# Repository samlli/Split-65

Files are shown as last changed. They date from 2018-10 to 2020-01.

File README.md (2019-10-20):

# split_65
split_65 (insert creative name here) is a split, 65% layout keyboard designed for improved ergonomics and typing comfort over extended periods of time.

<figure>
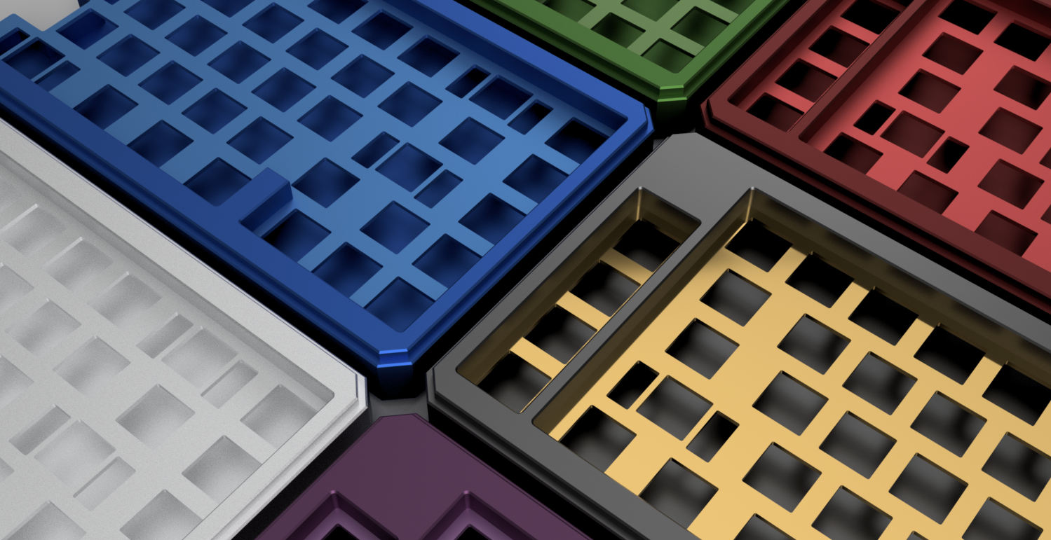
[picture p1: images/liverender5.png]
homepage
  
  <figcaption><i>maybe grey's not your taste - red and green and blue, oh my!</i></figcaption>
</figure>

It aims to remain loyal to the standard ansi layout, making the split_65 second nature to use.  The sturdy two part aluminum construction ensures that the keyboard will survive whatever torture is thrown at it over the years

<figure>
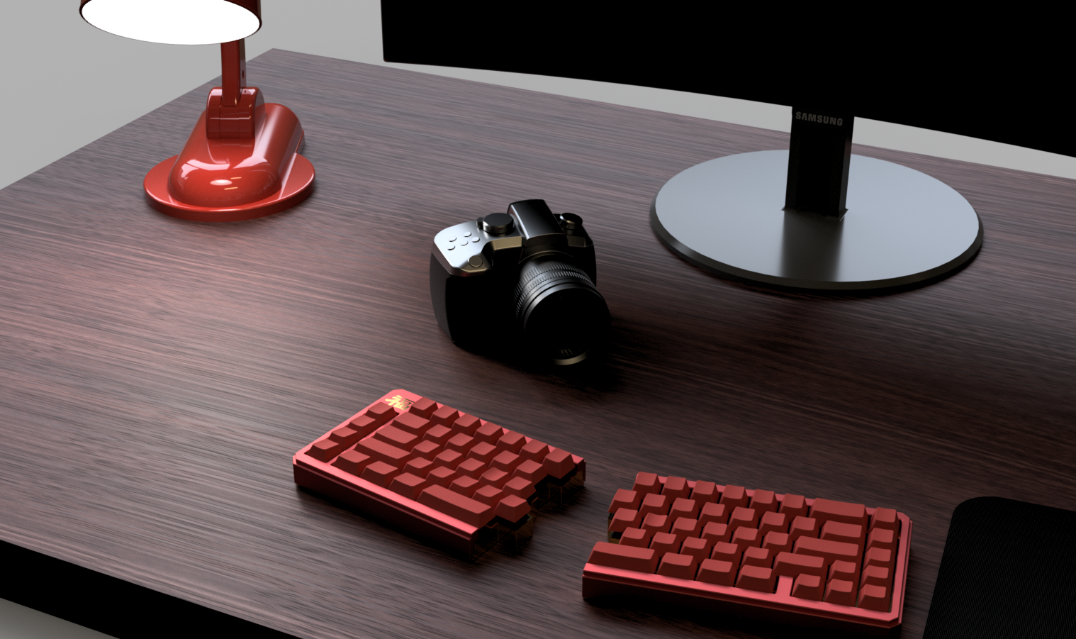
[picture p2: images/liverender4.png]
on the desk
  
  <figcaption><i>feels right at home on any desk</i></figcaption>
</figure>

## technical details

<figure>
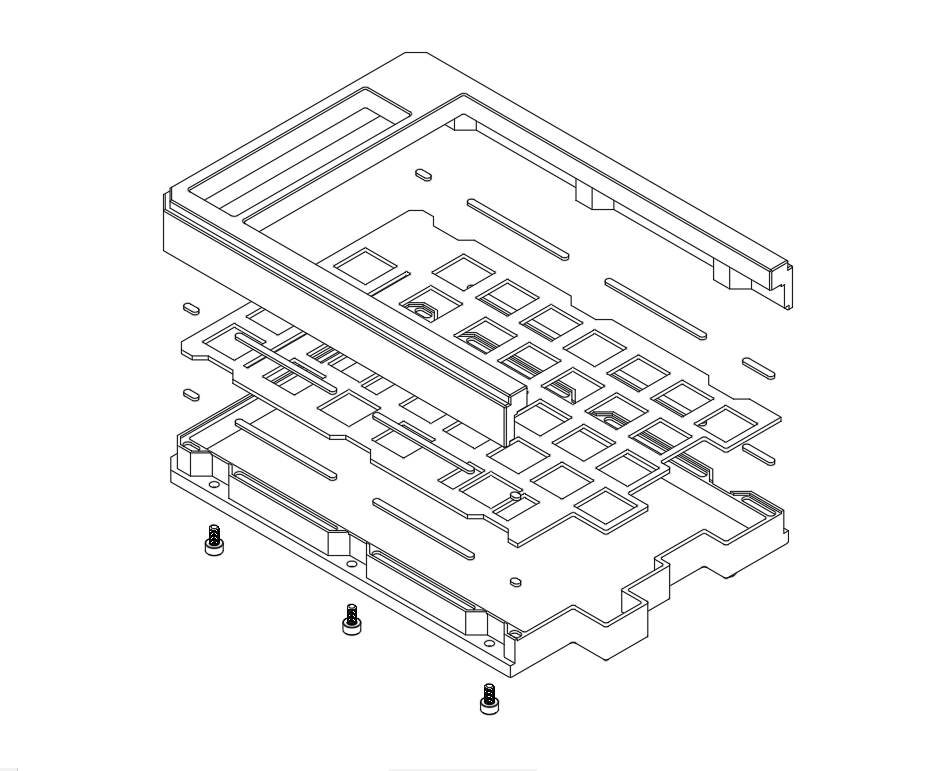
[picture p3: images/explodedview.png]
exploded view
  
  <figcaption><i>I just wanted to show off an exploded view</i></figcaption>
</figure>

Possible layouts are shown below - the pcb offers stepped caps lock, tsangan, and split backspace support, and users are free to mix and match layouts as needed to suit their needs.

<figure>
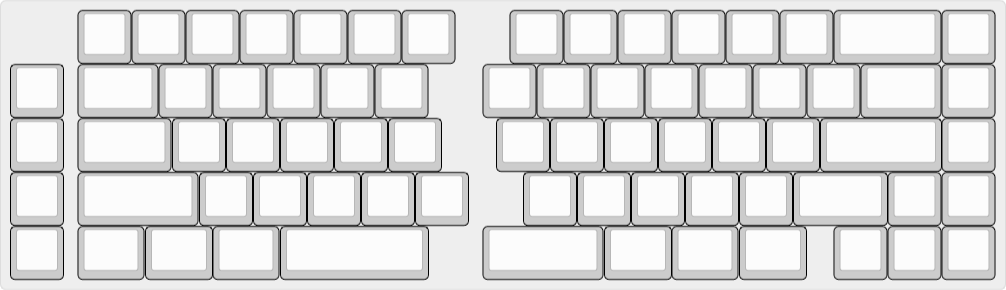
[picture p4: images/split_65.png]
layout
  
  <figcaption><i>possible layout one</i></figcaption>
</figure>

<figure>
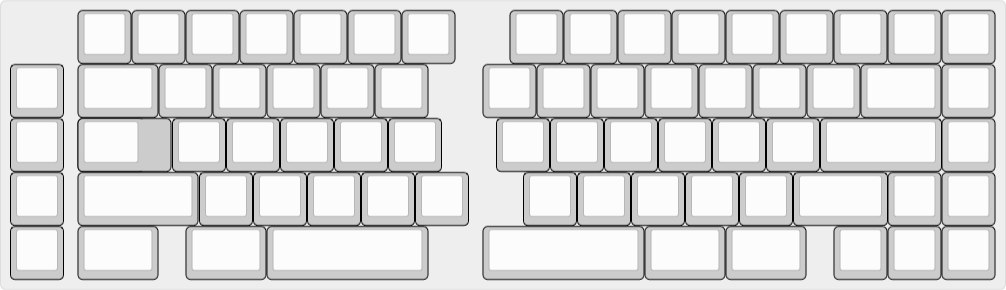
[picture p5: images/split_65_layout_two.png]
layout two
  
  <figcaption><i>possible layout two</i></figcaption>
</figure>

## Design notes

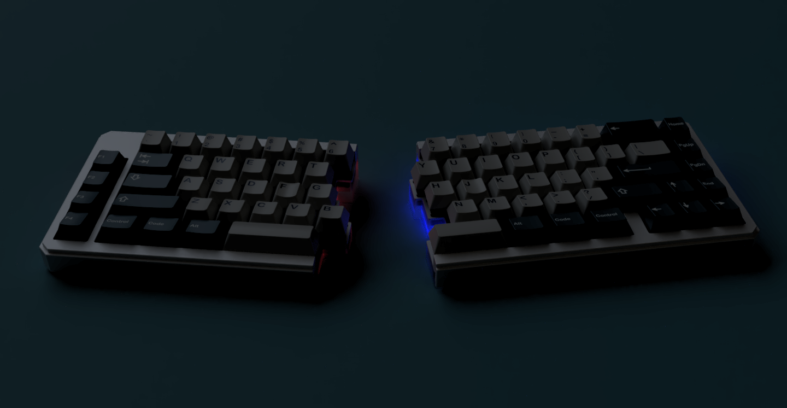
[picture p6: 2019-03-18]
images/ta90_poly_blank_render_1.png

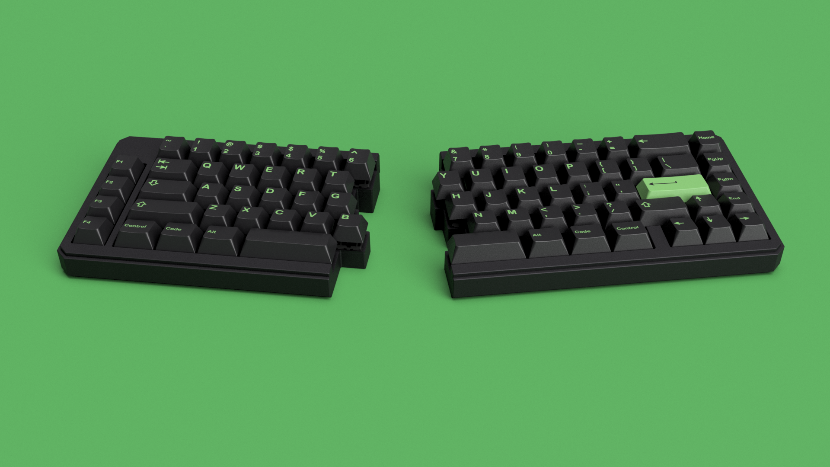
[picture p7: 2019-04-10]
images/terminal_blank_render_3.png

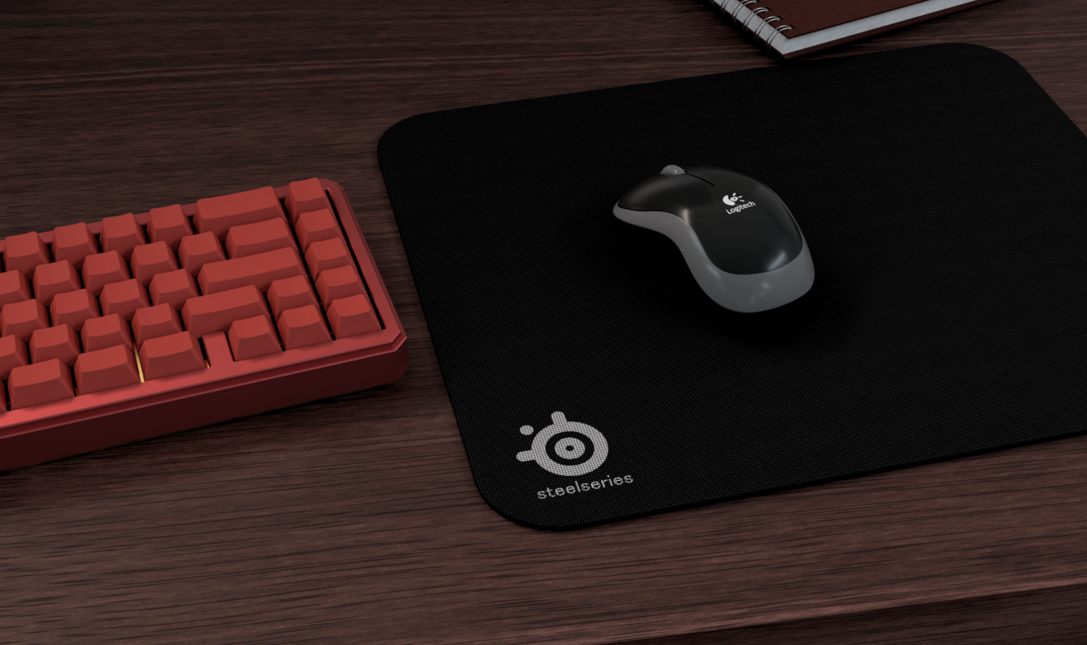
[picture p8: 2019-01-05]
images/liverender3.png

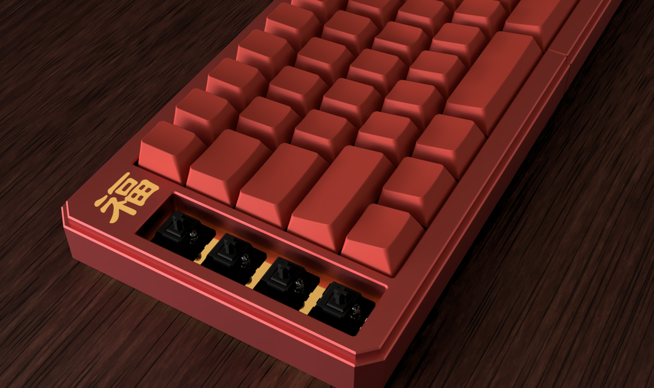
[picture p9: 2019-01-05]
images/render2.png

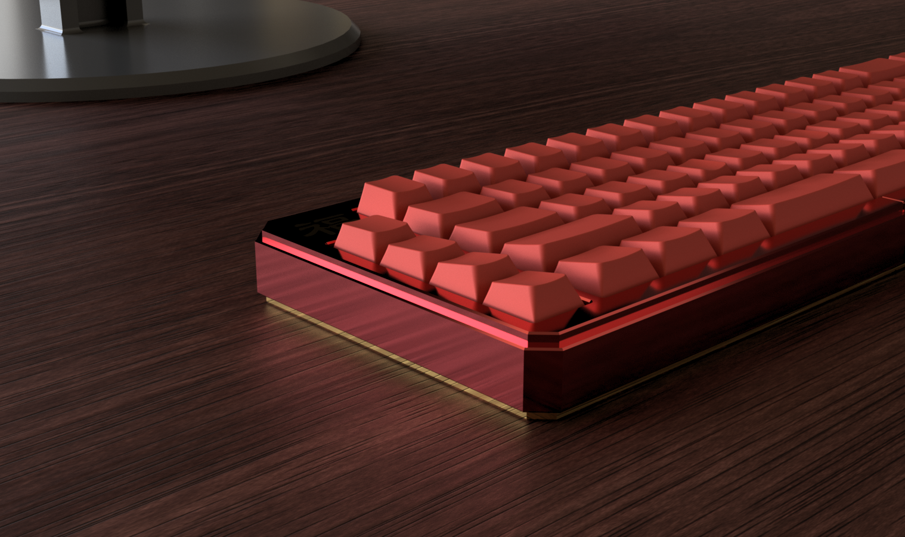
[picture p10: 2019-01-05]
images/liverender2.png

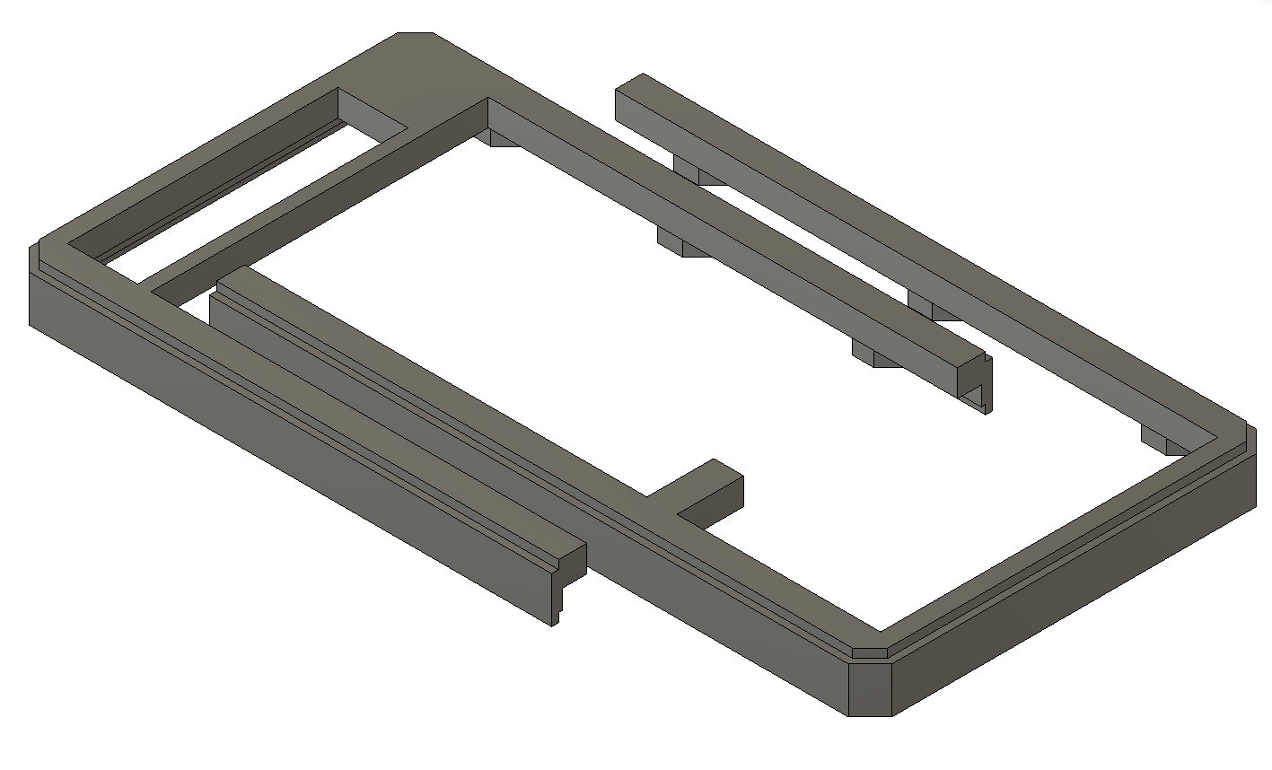
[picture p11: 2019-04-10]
images/tops.png

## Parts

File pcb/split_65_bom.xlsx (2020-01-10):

Designator | Manufacturer Part Number or Seeed SKU | Qty | Link
C1,C2,C8,C9 | 302010143 | 4
C3,C10 | 302010139 | 2
C4,C5,C6,C11,C12,C13 | 302010138 | 6
C7,C14 | 302010103 | 2
D0,D1,D2,D3,D4,D5,D6,D7,D8,D9,D10,D11,D12,D13,D14,D15,D16,D17,D18,D19,D20,D21,D22,D23,D24,D25,D26,D27,D28,D29,D30,D31,D32,D33,D35,D36,D37,D38,D39,D40,D41,D42,D43,D44,D45,D46,D47,D48,D49,D50,D51,D52,D53,D54,D55,D56,D57,D58,D59,D60,D61,D62,D63,D64,D65,D66,D67,D68,D69,D70,D71,D72,D73,D74,D75 | MMSD4148T1G | 75
D34,D76 | 304020028 | 2
F1,F2 | 307010002 | 2
R8,R9 | 301010306 | 2
R18 | 301010367 | 1
R24,R40,R69,R88 | 301010361 | 4
R38,R39,R86,R87 | 301010329 | 4
R41,R42,R89,R90 | 301012180 | 4
U1,U3 | ATMEGA32U4-AU | 2
U2,U4 | 304050022 | 2
USB1,USB2 | TYPE-C-31-M-12 | 2 | https://lcsc.com/product-detail/USB-Type-C_Korean-Hroparts-Elec-TYPE-C-31-M-12_C165948.html
Y1,Y2 | 306010049 | 2

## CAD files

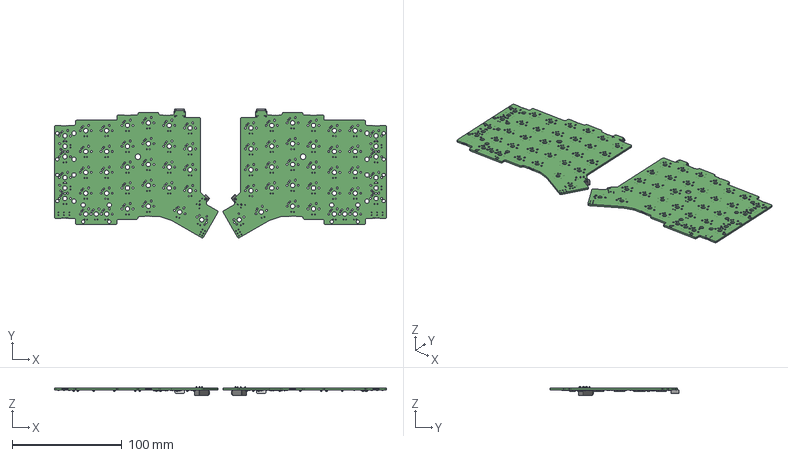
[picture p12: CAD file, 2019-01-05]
pcb/split_65.step
303.2 x 117.9 x 8.00 mm

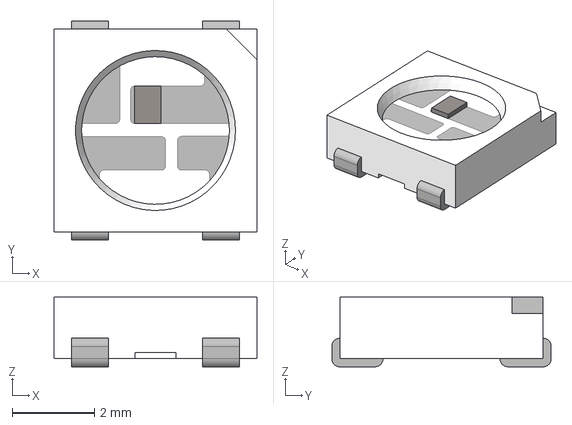
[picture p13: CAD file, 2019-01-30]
pcb/WS2812B.pretty-master/WS2812_RGB_LED_updated.stp
4.95 x 5.35 x 1.70 mm

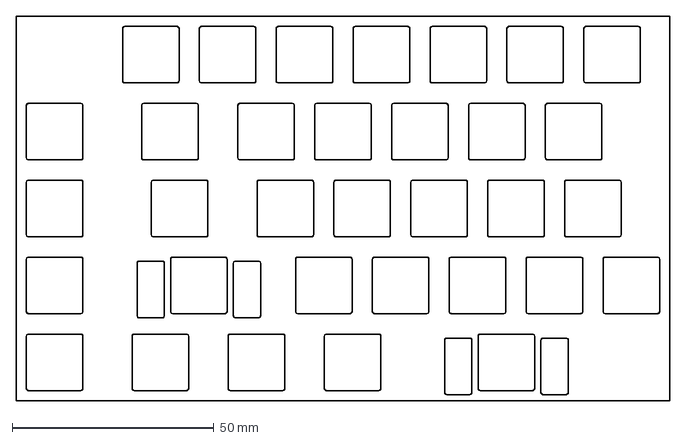
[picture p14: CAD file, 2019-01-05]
plategen/plate_left_1.dxf
161.9 x 95.2 mm

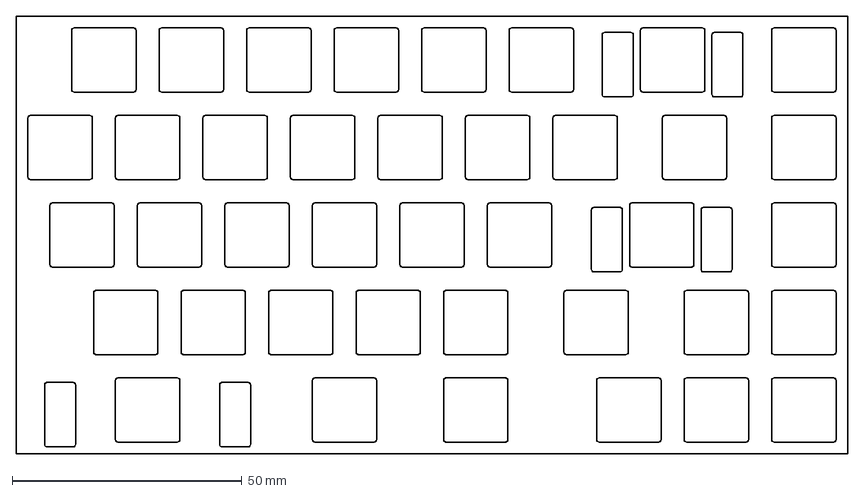
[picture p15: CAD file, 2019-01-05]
plategen/plate_right_2.dxf
181.0 x 95.2 mm

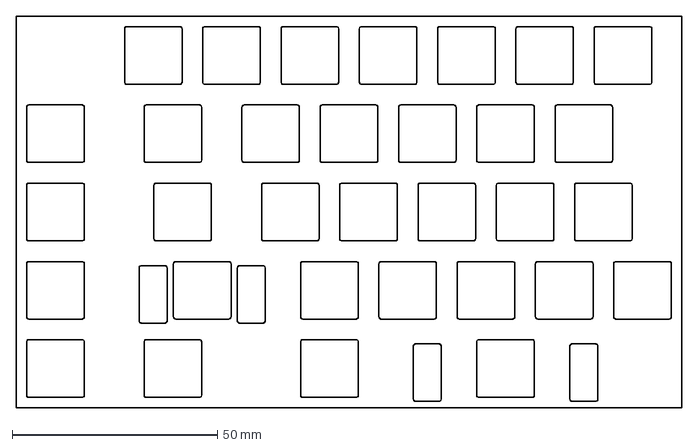
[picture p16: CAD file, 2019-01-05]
plategen/plate_left_2.dxf
161.9 x 95.2 mm

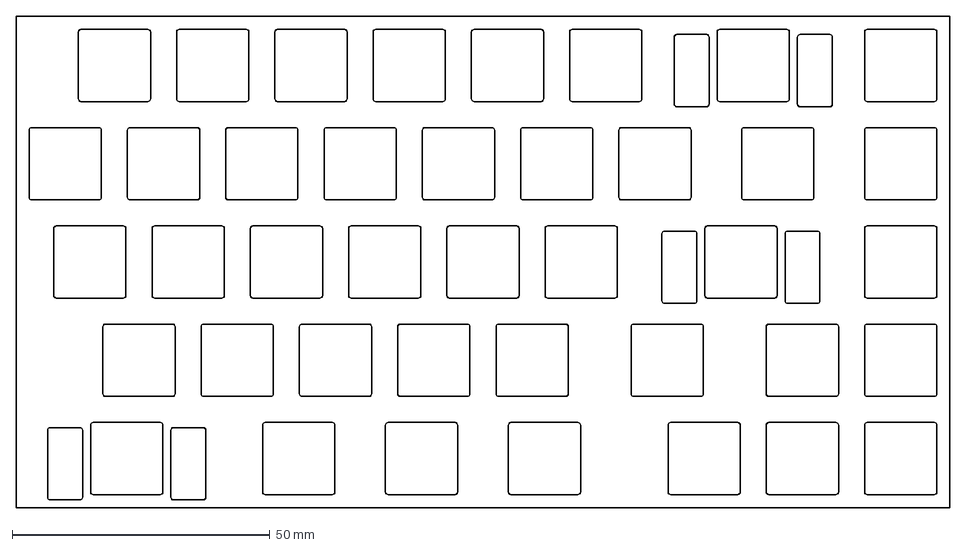
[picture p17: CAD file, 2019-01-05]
plategen/plate_right_1.dxf
181.0 x 95.2 mm

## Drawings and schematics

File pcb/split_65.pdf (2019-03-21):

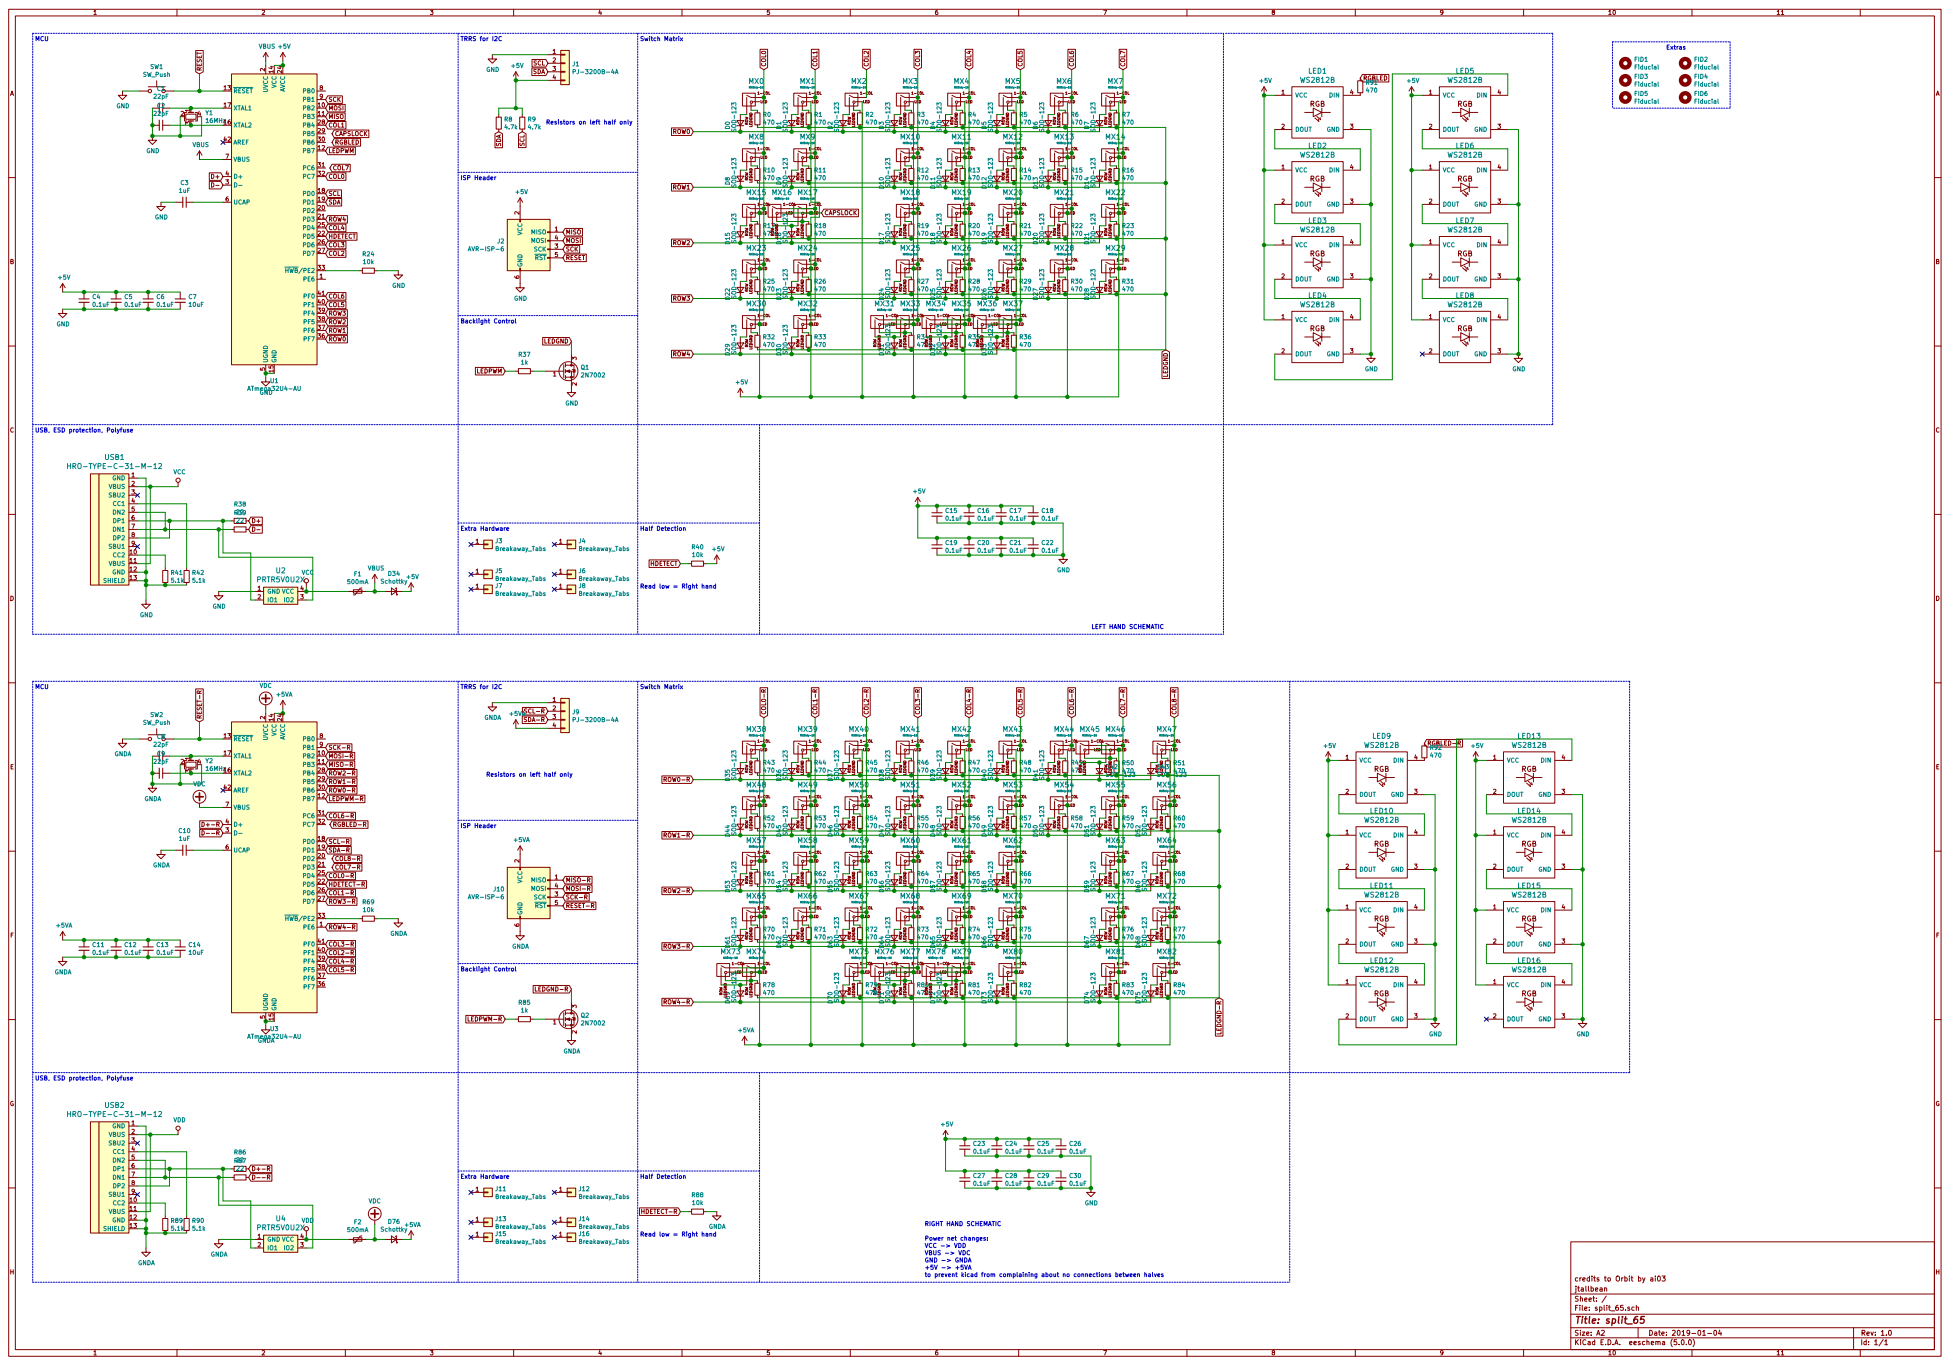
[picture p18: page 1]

Resistors on left half only LEDPWM

LED ROW LEDGND MX10 | LED ROW LEDGND MX11 | | LED ROW LEDGND MX12 | LED ROW LEDGND MX13

LED ROW LEDGND MX22 1-COL 470

LED ROW LEDGND MX25 | | LED ROW LEDGND MX26 | LED ROW LEDGND MX27

1-COL

USB, ESD protection, Polyfuse
HRO-TYPE-C-31-M-12 GND

J10 AVR-ISP-6 SCK-R MOSI-R MISO-R RESET-R

ROW2-R
Resistors on left half only LEDPWM-R

10k Read low = Right hand GNDA

Power net changes: VCC -> VDD

VBUS -> VDC GND -> GNDA

credits to Orbit by ai03
jtallbean
File: split_65.sch Sheet: /
Id: 1/1 Title: split_65

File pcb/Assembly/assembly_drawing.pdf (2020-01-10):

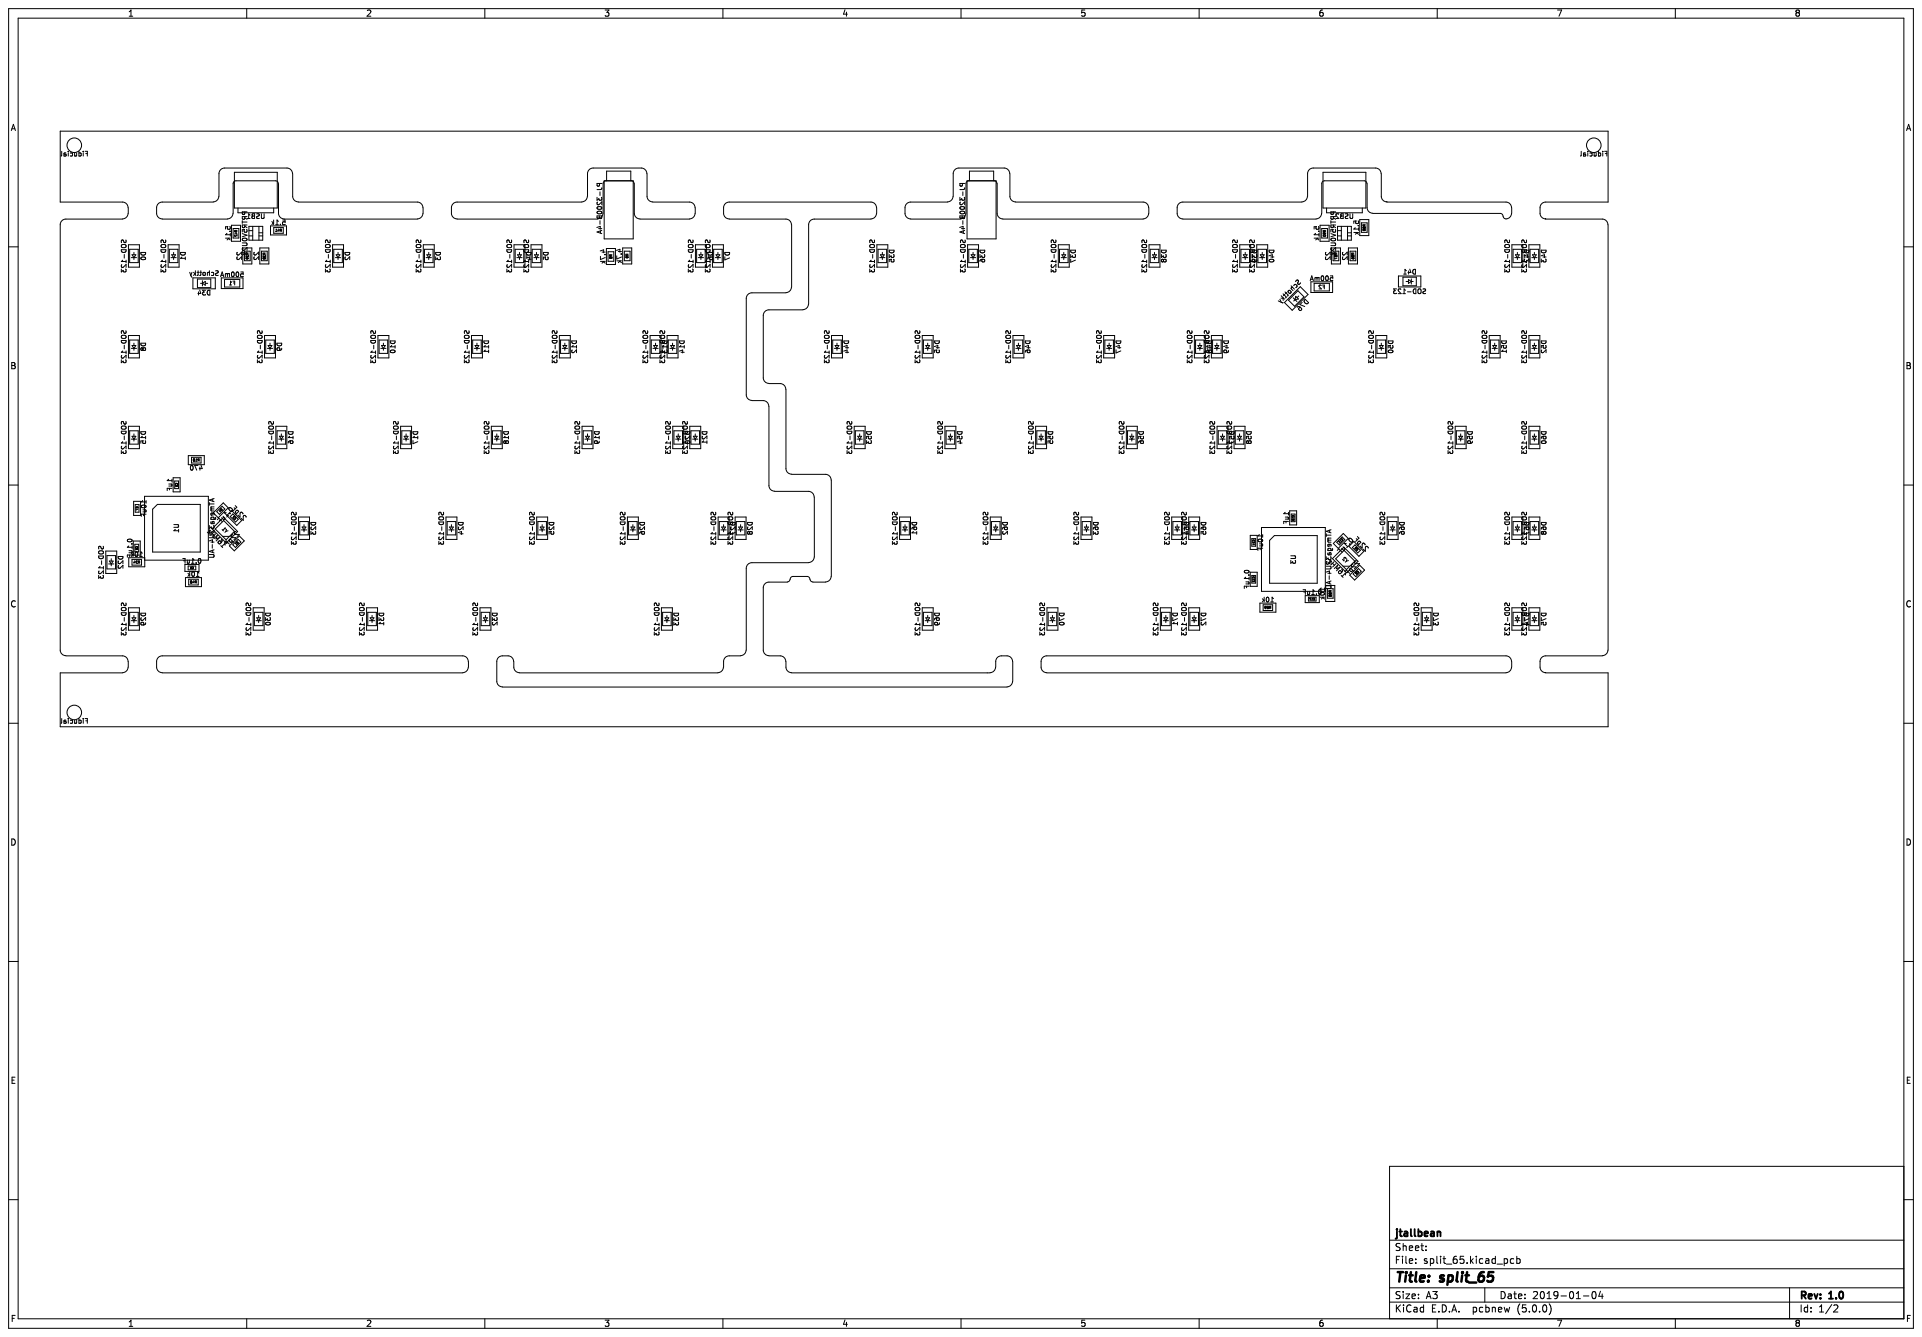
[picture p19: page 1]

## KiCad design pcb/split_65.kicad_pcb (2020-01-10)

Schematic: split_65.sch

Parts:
C1, C2, C8, C9: 22pF; C_0603_1608Metric
C3, C10: 1uF; C_0603_1608Metric
C4, C5, C6, C11, C12, C13: 0.1uF; C_0603_1608Metric
C7, C14: 10uF; C_0603_1608Metric
D0, D1, D2, D3, D4, D5, D6, D7, D8, D9, D10, D11, D12, D13, D14, D15, D16, D17, D18, D19, D20, D21, D22, D23, D24, D25, D26, D27, D28, D29, D30, D31, D32, D33, D35, D36, D37, D38, D39, D40, D41, D42, D43, D44, D45, D46, D47, D48, D49, D50, D51, D52, D53, D54, D55, D56, D57, D58, D59, D60, D61, D62, D63, D64, D65, D66, D67, D68, D69, D70, D71, D72, D73, D74, D75: SOD-123; D_SOD-123
D34, D76: Schottky; D_SOD-123
F1, F2: 500mA; Fuse_1206_3216Metric
FID1, FID2, FID3, FID4, FID5, FID6: Fiducial; Fiducial_1mm_Dia_2.54mm_Outer_CopperTop
J1, J9: PJ-3200B-4A
J2, J10: AVR-ISP-6; Reset_Pretty-Mask
J3, J4, J5, J6, J7, J8, J11, J12, J13, J14: Breakaway_Tabs; breakaway-mousebites
MX0, MX1, MX2, MX3, MX4, MX5, MX6, MX7, MX8, MX10, MX11, MX12, MX13, MX14, MX15, MX18, MX19, MX20, MX21, MX22, MX23, MX25, MX26, MX27, MX28, MX29, MX30, MX31, MX38, MX39, MX40, MX41, MX42, MX43, MX44, MX46, MX47, MX48, MX49, MX50, MX51, MX52, MX53, MX54, MX56, MX57, MX58, MX59, MX60, MX61, MX62, MX64, MX65, MX66, MX67, MX68, MX69, MX71, MX72, MX80, MX81, MX82: MXOnly-1U-NoLED
MX9, MX55, MX76, MX78: MXOnly-1U-NoLED; MXOnly-1.5U-NoLED
MX16: MXOnly-1U-NoLED; MXOnly-1.25U
MX17: MXOnly-1U-NoLED; MXOnly-1.75U-FLIPPED
MX24, MX63, MX74: MXOnly-1U-NoLED; MXOnly-2.25U-NoLED
MX32, MX33, MX34, MX35, MX75, MX77, MX79: MXOnly-1U-NoLED; MXOnly-1.25U-NoLED
MX36, MX73: MXOnly-1U-NoLED; MXOnly-3U-NoLED
MX37: MXOnly-1U-NoLED; MXOnly-2.75U-NoLED
MX45: MXOnly-1U-NoLED; MXOnly-2U-NoLED
MX70: MXOnly-1U-NoLED; MXOnly-1.75U-NoLED
R8, R9: 4.7k; R_0805_2012Metric
R18: 470; R_0805_2012Metric
R24, R40, R69, R88: 10k; R_0805_2012Metric
R38, R39, R86, R87: 22; R_0805_2012Metric
R41, R42, R89, R90: 5.1k; R_0805_2012Metric
U1, U3: ATmega32U4-AU; TQFP-44_10x10mm_P0.8mm
U2, U4: PRTR5V0U2X; SOT143B
USB1, USB2: HRO-TYPE-C-31-M-12; HRO-TYPE-C-31-M-12-Assembly
Y1, Y2: 16MHz; Crystal_SMD_3225-4Pin_3.2x2.5mm

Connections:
+5V: C4.1, C5.1, C6.1, C7.1, D34.1, J1.4, J2.2, R8.1, R9.1, R40.1, U1.14 (VCC), U1.24 (AVCC), U1.34 (VCC), U1.44 (AVCC)
+5VA: C11.1, C12.1, C13.1, C14.1, D76.1, J9.4, J10.2, U3.14 (VCC), U3.24 (AVCC), U3.34 (VCC), U3.44 (AVCC)
CAPSLOCK: MX16.3, MX17.3, U1.8 (PB0)
COL0: MX0.1, MX8.1, MX15.1, MX23.1, MX30.1, U1.31 (PC6)
COL0-R: MX38.1, MX48.1, MX57.1, MX65.1, MX73.1, MX74.1, U3.28 (PB4)
COL1: MX1.1, MX9.1, MX16.1, MX17.1, MX24.1, MX32.1, U1.29 (PB5)
COL1-R: MX39.1, MX49.1, MX58.1, MX66.1, U3.29 (PB5)
COL2: MX2.1, U1.28 (PB4)
COL2-R: MX40.1, MX50.1, MX59.1, MX67.1, MX75.1, U3.30 (PB6)
COL3: MX3.1, MX10.1, MX18.1, MX25.1, MX31.1, MX33.1, U1.27 (PD7)
COL3-R: MX41.1, MX51.1, MX60.1, MX68.1, MX76.1, MX77.1, U3.31 (PC6)
COL4: MX4.1, MX11.1, MX19.1, MX26.1, MX34.1, MX35.1, U1.26 (PD6)
COL4-R: MX42.1, MX52.1, MX61.1, MX69.1, MX78.1, MX79.1, U3.32 (PC7)
COL5: MX5.1, MX12.1, MX20.1, MX27.1, MX36.1, MX37.1, U1.25 (PD4)
COL5-R: MX43.1, MX53.1, MX62.1, MX70.1, MX80.1, U3.25 (PD4)
COL6: MX6.1, MX13.1, MX21.1, MX28.1, U1.20 (PD2)
COL6-R: MX44.1, MX54.1, U3.26 (PD6)
COL7: MX7.1, MX14.1, MX22.1, MX29.1, U1.21 (PD3)
COL7-R: MX45.1, MX46.1, MX55.1, MX63.1, MX71.1, MX81.1, U3.21 (PD3)
COL8-R: MX47.1, MX56.1, MX64.1, MX72.1, MX82.1, U3.20 (PD2)
D+: R38.1, U1.4 (D+)
D+-R: R86.1, U3.4 (D+)
D-: R39.1, U1.3 (D-)
D--R: R87.1, U3.3 (D-)
GND: C1.2, C2.2, C3.2, C4.2, C5.2, C6.2, C7.2, J1.1, J2.6, R18.2, R24.1, R41.2, R42.2, U1.5 (UGND), U1.15 (GND), U1.23 (GND), U1.35 (GND), U1.43 (GND), U2.1, USB1.1, USB1.12, USB1.13, Y1.2, Y1.4
GNDA: C8.2, C9.2, C10.2, C11.2, C12.2, C13.2, C14.2, J9.1, J10.6, R69.1, R88.1, R89.2, R90.2, U3.5 (UGND), U3.15 (GND), U3.23 (GND), U3.35 (GND), U3.43 (GND), U4.1, USB2.1, USB2.12, USB2.13, Y2.2, Y2.4
HDETECT: R40.2, U1.22 (PD5)
HDETECT-R: R88.2, U3.22 (PD5)
MISO: J2.1, U1.11 (PB3)
MISO-R: J10.1, U3.11 (PB3)
MOSI: J2.4, U1.10 (PB2)
MOSI-R: J10.4, U3.10 (PB2)
unnamed: C1.1, U1.17 (XTAL1), Y1.1
unnamed: C2.1, U1.16 (XTAL2), Y1.3
unnamed: C3.1, U1.6 (UCAP)
unnamed: C8.1, U3.17 (XTAL1), Y2.1
unnamed: C9.1, U3.16 (XTAL2), Y2.3
unnamed: C10.1, U3.6 (UCAP)
unnamed: D0.2, MX0.2
unnamed: D1.2, MX1.2
unnamed: D2.2, MX2.2
unnamed: D3.2, MX3.2
unnamed: D4.2, MX4.2
unnamed: D5.2, MX5.2
unnamed: D6.2, MX6.2
unnamed: D7.2, MX7.2
unnamed: D8.2, MX8.2
unnamed: D9.2, MX9.2
unnamed: D10.2, MX10.2
unnamed: D11.2, MX11.2
unnamed: D12.2, MX12.2
unnamed: D13.2, MX13.2
unnamed: D14.2, MX14.2
unnamed: D15.2, MX15.2
unnamed: D16.2, MX16.2, MX17.2
unnamed: D17.2, MX18.2
unnamed: D18.2, MX19.2
unnamed: D19.2, MX20.2
unnamed: D20.2, MX21.2
unnamed: D21.2, MX22.2
unnamed: D22.2, MX23.2
unnamed: D23.2, MX24.2
unnamed: D24.2, MX25.2
unnamed: D25.2, MX26.2
unnamed: D26.2, MX27.2
unnamed: D27.2, MX28.2
unnamed: D28.2, MX29.2
unnamed: D29.2, MX30.2
unnamed: D30.2, MX32.2
unnamed: D31.2, MX31.2, MX33.2
unnamed: D32.2, MX34.2, MX35.2
unnamed: D33.2, MX36.2, MX37.2
unnamed: D35.2, MX38.2
unnamed: D36.2, MX39.2
unnamed: D37.2, MX40.2
unnamed: D38.2, MX41.2
unnamed: D39.2, MX42.2
unnamed: D40.2, MX43.2
unnamed: D41.2, MX44.2
unnamed: D42.2, MX45.2, MX46.2
unnamed: D43.2, MX47.2
unnamed: D44.2, MX48.2
unnamed: D45.2, MX49.2
unnamed: D46.2, MX50.2
unnamed: D47.2, MX51.2
unnamed: D48.2, MX52.2
unnamed: D49.2, MX53.2
unnamed: D50.2, MX54.2
unnamed: D51.2, MX55.2
unnamed: D52.2, MX56.2
unnamed: D53.2, MX57.2
unnamed: D54.2, MX58.2
unnamed: D55.2, MX59.2
unnamed: D56.2, MX60.2
unnamed: D57.2, MX61.2
unnamed: D58.2, MX62.2
unnamed: D59.2, MX63.2
unnamed: D60.2, MX64.2
unnamed: D61.2, MX65.2
unnamed: D62.2, MX66.2
unnamed: D63.2, MX67.2
unnamed: D64.2, MX68.2
unnamed: D65.2, MX69.2
unnamed: D66.2, MX70.2
unnamed: D67.2, MX71.2
unnamed: D68.2, MX72.2
unnamed: D69.2, MX73.2, MX74.2
unnamed: D70.2, MX75.2
unnamed: D71.2, MX76.2, MX77.2
unnamed: D72.2, MX78.2, MX79.2
unnamed: D73.2, MX80.2
unnamed: D74.2, MX81.2
unnamed: D75.2, MX82.2
unnamed: MX16.4, MX17.4, R18.1
unnamed: R24.2, U1.33 (~HWB~/PE2)
unnamed: R38.2, U2.2, USB1.6, USB1.8
unnamed: R39.2, U2.3, USB1.5, USB1.7
unnamed: R41.1, USB1.10
unnamed: R42.1, USB1.4
unnamed: R69.2, U3.33 (~HWB~/PE2)
unnamed: R86.2, U4.2, USB2.6, USB2.8
unnamed: R87.2, U4.3, USB2.5, USB2.7
unnamed: R89.1, USB2.10
unnamed: R90.1, USB2.4
RESET: J2.5, U1.13 (~RESET)
RESET-R: J10.5, U3.13 (~RESET)
ROW0: D0.1, D1.1, D2.1, D3.1, D4.1, D5.1, D6.1, D7.1, U1.39 (PF4)
ROW0-R: D35.1, D36.1, D37.1, D38.1, D39.1, D40.1, D41.1, D42.1, D43.1, U3.1 (PE6)
ROW1: D8.1, D9.1, D10.1, D11.1, D12.1, D13.1, D14.1, U1.40 (PF1)
ROW1-R: D44.1, D45.1, D46.1, D47.1, D48.1, D49.1, D50.1, D51.1, D52.1, U3.41 (PF0)
ROW2: D15.1, D16.1, D17.1, D18.1, D19.1, D20.1, D21.1, U1.41 (PF0)
ROW2-R: D53.1, D54.1, D55.1, D56.1, D57.1, D58.1, D59.1, D60.1, U3.40 (PF1)
ROW3: D22.1, D23.1, D24.1, D25.1, D26.1, D27.1, D28.1, U1.32 (PC7)
ROW3-R: D61.1, D62.1, D63.1, D64.1, D65.1, D66.1, D67.1, D68.1, U3.36 (PF7)
ROW4: D29.1, D30.1, D31.1, D32.1, D33.1, U1.30 (PB6)
ROW4-R: D69.1, D70.1, D71.1, D72.1, D73.1, D74.1, D75.1, U3.27 (PD7)
SCK: J2.3, U1.9 (PB1)
SCK-R: J10.3, U3.9 (PB1)
SCL: J1.2, R9.2, U1.18 (PD0)
SCL-R: J9.2, U3.18 (PD0)
SDA: J1.3, R8.2, U1.19 (PD1)
SDA-R: J9.3, U3.19 (PD1)
VBUS: D34.2, F1.1, U1.2 (UVCC), U1.7 (VBUS)
VCC: F1.2, U2.4, USB1.2, USB1.11
VDC: D76.2, F2.1, U3.2 (UVCC), U3.7 (VBUS)
VDD: F2.2, U4.4, USB2.2, USB2.11

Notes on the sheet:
ISP Header
TRRS for I2C
MCU
USB, ESD protection, Polyfuse
Resistors on left half only
Switch Matrix
Extra Hardware
LEFT HAND SCHEMATIC
RIGHT HAND SCHEMATIC Power net changes: VCC -> VDD VBUS -> VDC GND -> GNDA +5V -> +5VA to prevent kicad from complaining about no connections between halves
Half Detection
Read low = Right hand
Extras

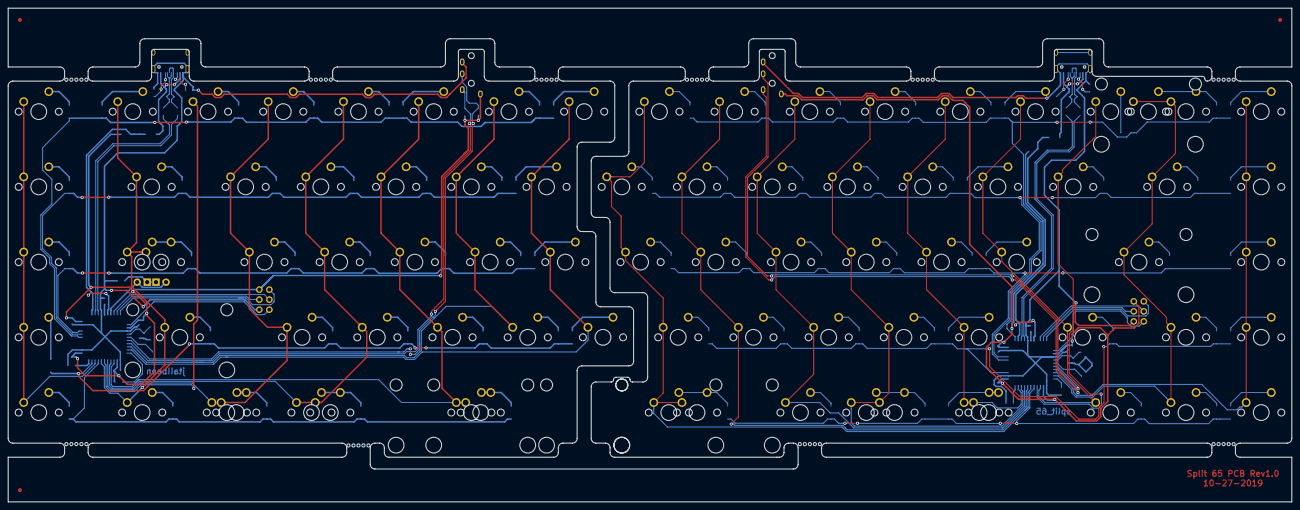
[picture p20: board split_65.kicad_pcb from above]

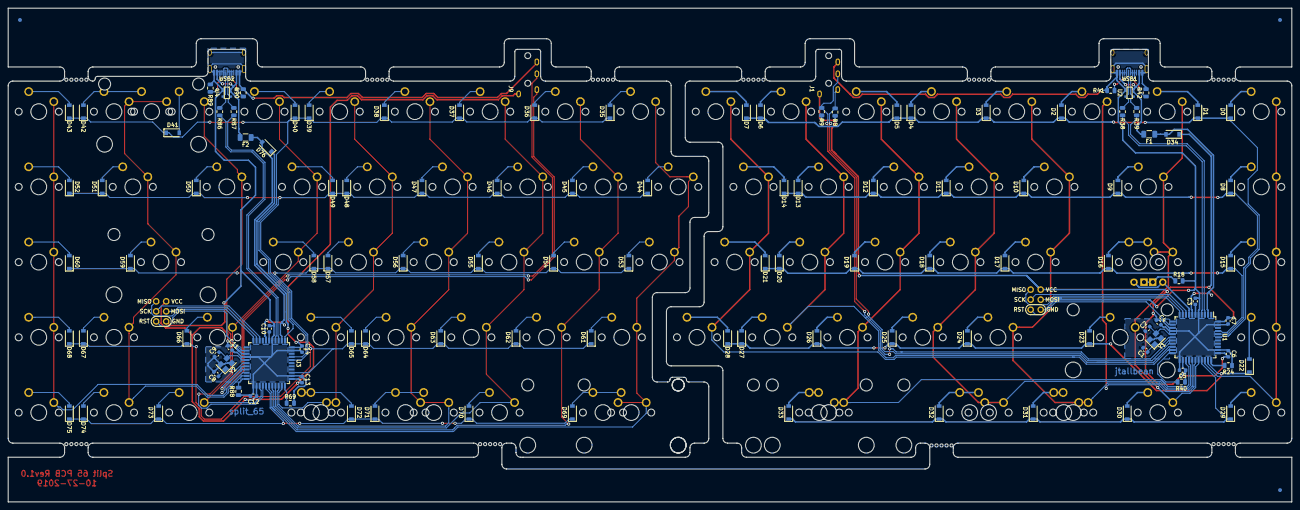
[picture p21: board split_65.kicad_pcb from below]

Board: 2 copper layers, 325.0 x 125.0 mm, 219 parts (133 on the bottom side), 146 nets.

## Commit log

2018-10-21 begin pcb schematic
    [split_65.kicad_pcb, split_65.sch]
2018-11-18 switches, diodes schematic
2018-11-19 assigned fp and pcbnew layout for switches
    [split_65.sch]
2018-11-20 setup schematic hierarchies, update images
    [left.sch, right.sch, split_65.kicad_pcb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]
2019-01-05 add cool renders, complete pcb schematic
    [Orbit-B.Adhes.dxf, Orbit-B.Mask.dxf, Orbit-B.Paste.dxf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]
2019-01-08 laid out diodes and resistors
    [split_65.kicad_pcb, split_65.sch]
2019-01-12 did edge cuts
    [split_65.kicad_pcb, split_65.sch]
2019-01-13 edge cuts, route usb
    [split_65.kicad_pcb]
2019-01-22 add switch, edit models
    [split_65.kicad_pcb, split_65.sch]
2019-01-27 add resistor to rst, rgb underglow
    [split_65.kicad_pcb, split_65.sch]
2019-01-30 added rgb underglow and step files
    [WS2812_RGB_LED_updated.stp, split_65.kicad_pcb, split_65.sch]
2019-02-01 more traces
    [split_65.kicad_pcb, split_65.sch]
2019-02-02 generated step files
    [Orbit-B.Adhes.dxf, Orbit-B.Mask.dxf, Orbit-B.Paste.dxf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]
2019-02-04 moved usb/trrs port closer in
    [split_65.kicad_pcb]
2019-02-23 break out mcu pins
    [split_65.kicad_pcb]
2019-03-18 added more renders, changed pcb layout
    [split_65.kicad_pcb, split_65.sch]
2019-03-21 pdf of schematic
2019-04-10 reset layouts
    [split_65.kicad_pcb]
2019-04-10 laid out ws2812b
    [split_65.kicad_pcb]
2019-05-16 removed underglow and backlight, routed left hand
    [split_65.kicad_pcb, split_65.sch]
2019-05-17 routed right hand side
    [split_65.kicad_pcb, split_65.sch]
2019-05-17 added step files, combined and panelized
    [split_65.kicad_pcb, split_65.sch]
2019-10-20 update pcb traces
    [split_65.kicad_pcb]
2019-10-27 update silkscreen
    [split_65.kicad_pcb]
2020-01-10 Added BOM, gerbers, and position
    [split_65-B.Cu.gbl, split_65-B.Mask.gbs, split_65-B.Paste.gbp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]
